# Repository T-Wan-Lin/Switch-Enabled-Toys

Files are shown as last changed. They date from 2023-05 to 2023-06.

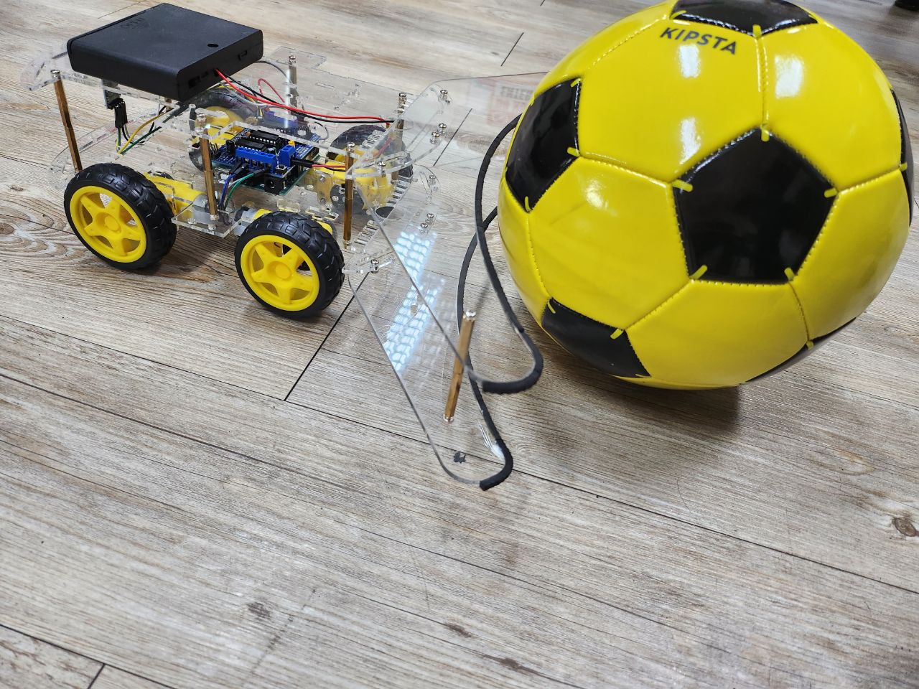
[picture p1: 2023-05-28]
docs/pictures/prototype_showcase/IMAGE 2023-05-28 16:13:55.jpg

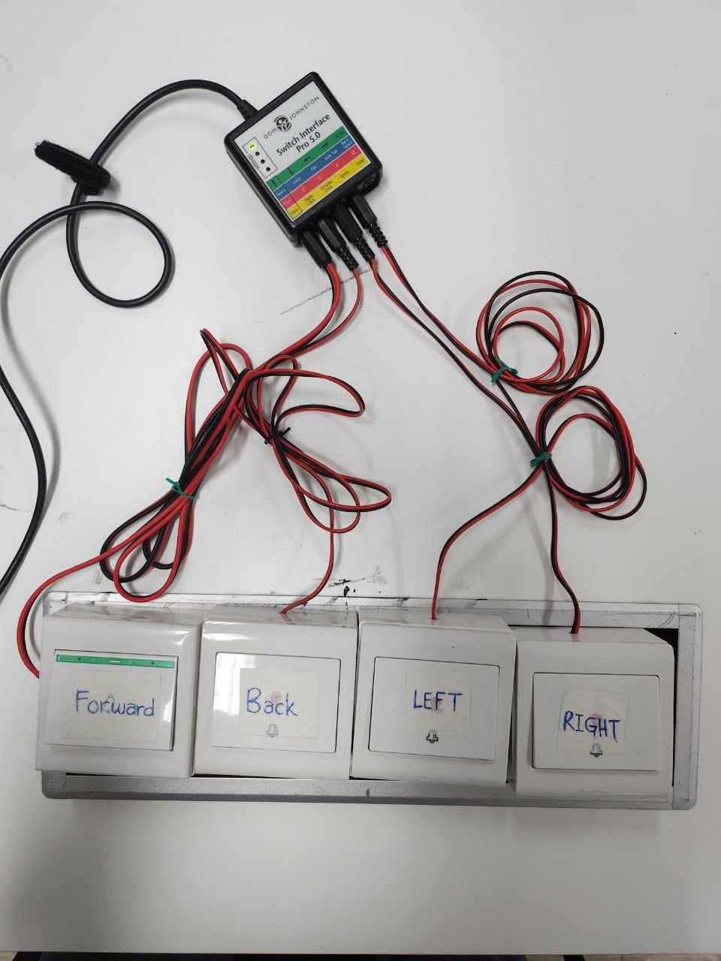
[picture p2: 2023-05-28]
docs/pictures/Switch Interface.jpg

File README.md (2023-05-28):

# Switch-Enabled-Toys: An EGSC Project done in collaboration with Rainbow Centre

## About EGSC 
EGSC (Engineering Good Student Chapters) is an initiative by Engineering Good, a Singapore-based non-profit organization. EGSC aims to engage students in engineering and technology fields to create positive social impact. Through their student chapters, they provide opportunities for students to collaborate, develop innovative solutions, and contribute to various social causes. Visit their [website](https://engineeringgood.org/about-us/student-chapters/) for more information.

## About Rainbow Centre
The Rainbow Centre, located in Singapore, is a non-profit organization dedicated to supporting individuals with disabilities and their families. Through a range of educational, therapeutic, and vocational services, they strive to empower individuals with special needs and promote their inclusion in society. Visit the [Rainbow Centre website](https://rainbowcentre.org.sg/) for more information.
 for more information.
## About the Project

The project focuses on creating switch-enabled toys for students of Rainbow Centre with multiple disabilities.
Due to their limited mobility, they are only able to watch from the sidelines as their peers engage in physical activities. 
We are currently working on a remote-controlled device that can be controlled by wheelchair-bound students to launch a ball into a net 
just by pressing a few buttons. We hope that with this device, they can engage more meaningfully in sports, 
and learn about directional changes as well as cause and effect.

For technical documentation, visit the `docs` [folder](https://github.com/T-Wan-Lin/Switch-Enabled-Toys/tree/docs/docs) in this repository. 

## Project members
The following are the contributing members to this project:

1. Tan Wan Lin

2. Kwa Minyi, Samantha

3. Cheran Lee Yen-ning

4. Hoe Mun

5. Pulipaka Sai Nandini

Should you need additional guidance, do not hesitate to contact us or raise an issue on Github.

## Acknowledgement

We would like to thank EGSC for giving us this invaluable opportunity as well as Mr Koh and Mr Khoo for their guidance.

Resources used:

How to build a DIY Bluetooth car: https://www.youtube.com/watch?v=Q36NbjPMV5k

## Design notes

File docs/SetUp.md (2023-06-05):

# Quick Start

## System requirements (should the designated device not be used)
1. Ensure that you have Python 3.70 (and above) installed. Visit this [site](https://www.python.org/downloads/release/python-370/) to install Python (including IDLE).
2. (Only if you have to upload the Arduino code, else, skip this step) Ensure that Arduino IDE is installed on your personal computer.
3. Ensure that these 2 python modules are installed: pyserial (using _pip install pyserial_ on commmand prompt) and pynput (using _pip install pynput_ on command prompt) for the program to run. (If pip is not recognised, use _py -m pip install [packagename]_ on command prompt instead)

## Instructions for use

 If the designated device is used,

1. Plug in the switch interface on the *RIGHT* USB port. This is the COM5 port that will be used for Bluetooth communication. Should any other USB ports be used, change the port number accordingly in the Controller.py file. To find which port the switch interface is connected to visit this [site](https://help.fleetmon.com/en/articles/2010900-how-do-i-get-my-com-port-number-windows)

2. Ensure that the computer's Bluetooth is ON and it is connected to a device named `HC-05`. Should you need a PIN to connect to the device, it is either `0000` or `1234`.

3. Plug the switches into the module. Ensure that the FIRST light on the switch interface module is GREEN as shown in this [picture](https://github.com/T-Wan-Lin/Switch-Enabled-Toys/blob/docs/docs/pictures/Switch%20Interface.jpg). If it is not, use the button on the top right corner of the switch module to switch between the modes.

4. Run the executable* file. Press the switches. Give the bot some time to receive the first signals (latency). If the executable file cannot be located, proceed to step 5.

5. Download the Controller.py file and put it in the Desktop directory (preferable). Open the file in IDLE. In the uppermost toolbar, click `Run` and in the dropdown, click `Run Module`. Should there be no errors, `Start` should be printed. Should there be errors (in red text) check if the relevant python modules are installed or if the Bluetooth connection is working. This step applies to other computers that are used other than the designated one.

6. Press the switches to move the bot. Give the bot some time to receive the first signals (latency).

*To create the executable file for easier usage of Controller.py file, the python module - pyinstaller has to be installed (using _pip install pyinstaller_ on command prompt). (If pip is not recognised, use _py -m pip install pyinstaller_ on command prompt instead) Subsequently, in command prompt, change to the directory of the Controller.py file (using _cd [file directory]_) and run the following code (_pyinstaller --onefile Controller.py_) [Reference: https://datatofish.com/executable-pyinstaller/]

## Uploading of Code 

NOTE: This section is relevant in the case the Arduino Board is forcefully reset.

Should the reset button be pressed on either the motor shield or the Arduino board, connect the Arduino Board with the black cable provided to your computer. 

Steps: 

1. Download the ENTIRE folder called `EGSC_car` from the G-Drive folder or this repository and place it in the Desktop directory.
2. Open it with Arduino IDE, which should be installed.
3. Follow the instructions provided at the top of the EGSC_car.ino file to install the libraries before the upload.
4. Select the correct board and port.
5. Upload the code. 

You may visit this [site](https://support.arduino.cc/hc/en-us/articles/4733418441116-Upload-a-sketch-in-Arduino-IDE) for more detailed steps on troubleshooting.

Back-up code can be found in [G-Drive folder](https://drive.google.com/drive/folders/1xDtzrKRc55RQwkxslrCCrbxYAzH-E_bL?usp=sharing)

## Glossary
1. IDE: Integrated Development Environment
2. IDLE: Python IDE

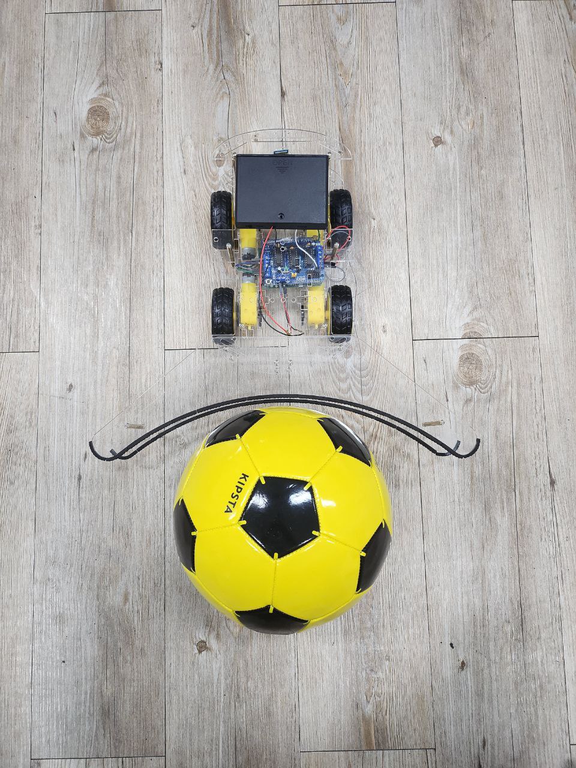
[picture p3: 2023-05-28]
docs/pictures/prototype_showcase/IMAGE 2023-05-28 16:13:47.jpg

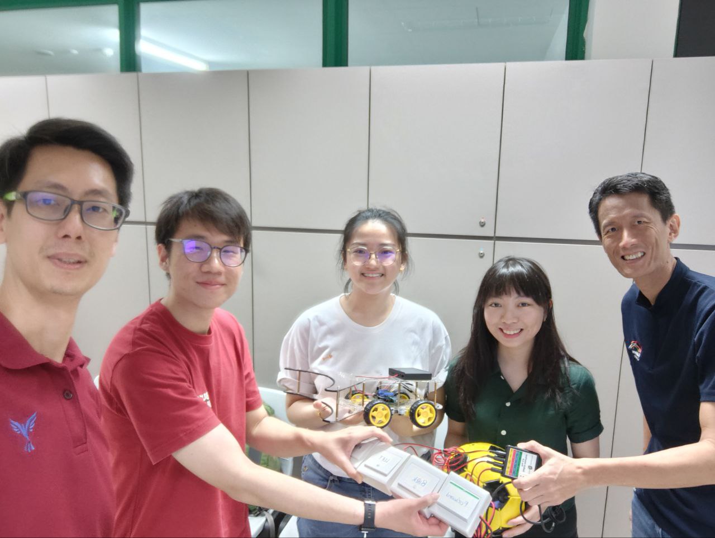
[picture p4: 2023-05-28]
docs/pictures/prototype_showcase/IMAGE 2023-05-28 16:19:57.jpg

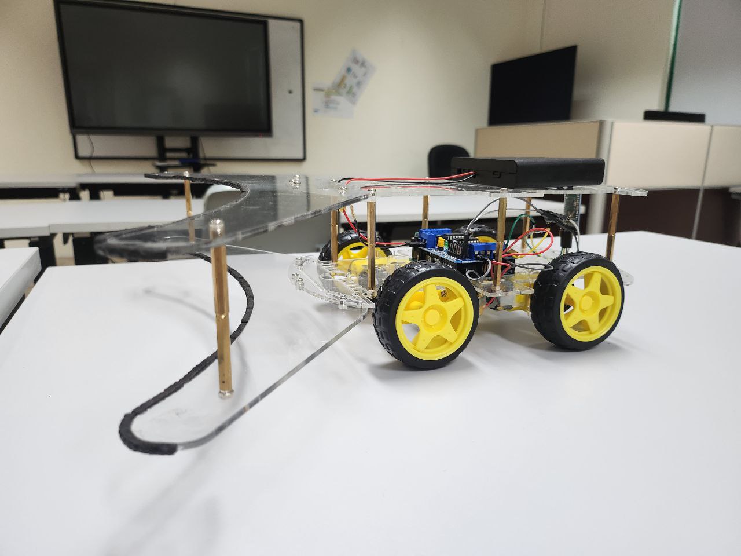
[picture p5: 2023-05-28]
docs/pictures/prototype_showcase/IMAGE 2023-05-28 16:13:51.jpg

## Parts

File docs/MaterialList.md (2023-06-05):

The following are the components used for the prototype:

|  No.  | Materials | Quantity  |
| :---: | :---: | :---: |
| 1 | Acrylic Chassis | 2* |
| 2 | Wheel | 4 |
| 3 | AA Batteries** | 6 |
| 4 | AA Battery Pack | 1 |
| 5 | Jumper Wires | As needed |
| 6 | C-frame*** | 2 |
| 7 | Rubber Lining along C-frame | As needed |
| 8 | Arduino Uno | 1 |
| 9 | Arduino L293D DC Motor Driver Shield | 1 |
|  10 | HC-05 Bluetooth Module | 1 |
|  11 | Nuts, bolts, hex brass screws | As needed |
|  12 |  Don Johnston Switch Interface Pro | 1 |
|  13 | Switches | 4 |
|  14 | Motor | 4 |

```
* One for lower and one for upper deck 

** Note: 9V is the minimum voltage needed to power the prototype but cannot be replaced with a single 9V battery 
cell due to limitations uncovered during real-life testing.

*** Using the c-frame dxf file, laser cut on acrylic sheet 
```

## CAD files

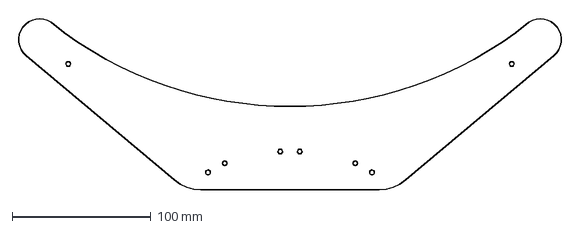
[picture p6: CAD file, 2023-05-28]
docs/cframe/C-Frame.dxf
394.1 x 124.8 mm

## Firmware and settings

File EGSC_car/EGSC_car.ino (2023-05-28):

//Arduino Bluetooth Controlled Car
//Before uploading the code you have to install the necessary library
//AFMotor Library https://learn.adafruit.com/adafruit-motor-shield/library-install 
//ENSURE THAT THE BLUETOOTH MODULE IS DISCONNECTED FROM THE BOARD BEFORE UPLOAD. To do so, simply disconnect either one of the jumper wires.

#include <AFMotor.h>

//initialise motors pin
AF_DCMotor motor1(1, MOTOR12_1KHZ); 
AF_DCMotor motor2(2, MOTOR12_1KHZ); 
AF_DCMotor motor3(3, MOTOR34_1KHZ);
AF_DCMotor motor4(4, MOTOR34_1KHZ);

char command; 

void setup() 
{       
  Serial.begin(9600);  //Set the baud rate to your Bluetooth module.
}

void loop(){
  if(Serial.available() > 0){ 
    command = Serial.read(); 
    Stop(); //initialize with motors stoped
    //Change pin mode only if new command is different from previous.   
    //Serial.println(command);
    switch(command){
    case 'F':  
      forward();
      break;
    case 'B':  
       back();
      break;
    case 'L':  
      left();
      break;
    case 'R':
      right();
      break;
    }
  } 
}

void forward()
{
  motor1.setSpeed(255); //Define maximum velocity
  motor1.run(FORWARD); //rotate the motor clockwise
  motor2.setSpeed(255); //Define maximum velocity
  motor2.run(FORWARD); //rotate the motor clockwise
  motor3.setSpeed(255);//Define maximum velocity
  motor3.run(FORWARD); //rotate the motor clockwise
  motor4.setSpeed(255);//Define maximum velocity
  motor4.run(FORWARD); //rotate the motor clockwise
}

void back()
{
  motor1.setSpeed(255); //Define maximum velocity
  motor1.run(BACKWARD); //rotate the motor anti-clockwise
  motor2.setSpeed(255); //Define maximum velocity
  motor2.run(BACKWARD); //rotate the motor anti-clockwise
  motor3.setSpeed(255); //Define maximum velocity
  motor3.run(BACKWARD); //rotate the motor anti-clockwise
  motor4.setSpeed(255); //Define maximum velocity
  motor4.run(BACKWARD); //rotate the motor anti-clockwise
}

void left()
{
  motor1.setSpeed(255); //Define maximum velocity
  motor1.run(BACKWARD); //rotate the motor anti-clockwise
  motor2.setSpeed(255); //Define maximum velocity
  motor2.run(BACKWARD); //rotate the motor anti-clockwise
  motor3.setSpeed(255); //Define maximum velocity
  motor3.run(FORWARD);  //rotate the motor clockwise
  motor4.setSpeed(255); //Define maximum velocity
  motor4.run(FORWARD);  //rotate the motor clockwise
}

void right()
{
  motor1.setSpeed(255); //Define maximum velocity
  motor1.run(FORWARD); //rotate the motor clockwise
  motor2.setSpeed(255); //Define maximum velocity
  motor2.run(FORWARD); //rotate the motor clockwise
  motor3.setSpeed(255); //Define maximum velocity
  motor3.run(BACKWARD); //rotate the motor anti-clockwise
  motor4.setSpeed(255); //Define maximum velocity
  motor4.run(BACKWARD); //rotate the motor anti-clockwise
} 

void Stop()
{
  motor1.setSpeed(0); //Define minimum velocity
  motor1.run(RELEASE); //stop the motor when release the button
  motor2.setSpeed(0); //Define minimum velocity
  motor2.run(RELEASE); //rotate the motor clockwise
  motor3.setSpeed(0); //Define minimum velocity
  motor3.run(RELEASE); //stop the motor when release the button
  motor4.setSpeed(0); //Define minimum velocity
  motor4.run(RELEASE); //stop the motor when release the button
}

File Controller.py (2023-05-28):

import serial
import time
from pynput import keyboard
 
evenement=""
print("Start")
port="COM3" #This will be different for various devices and on windows it will probably be a COM port. CHANGE THIS LINE ONLY
bluetooth=serial.Serial(port, 9600)#Start communications with the bluetooth unit
print("Connected")
bluetooth.flushInput() #This gives the bluetooth a little kick
result = str(0)
 
def on_key_release(key):
    global result
    #print('released %s' % key)
    #result ='released %s' % key+'\n'
    if result !='stop': #or result == str(2)+'\n' or result == str(3)+'\n' or result == str(4)+'\n':
       result = 'stop'
       print(result)
       result_bytes = result.encode('utf_8')
       bluetooth.write(result_bytes)
 
def on_key_pressed(key):
    global result       
    #print('pressed %s' % key)
    result1 ='%s' % key
    if result == 'stop':
        if result1=='Key.up' :
           result = 'F'
           print(result)
        if result1=='Key.down' :
           result = 'B'
           print(result)
        if result1=='Key.left' :
           result = 'R'
           print(result)
        if result1=='Key.right' :
           result = 'L'
           print(result)         
        result_bytes = result.encode('utf_8')
        bluetooth.write(result_bytes)
 
with keyboard.Listener(on_release = on_key_release,on_press=on_key_pressed) as listener:
    listener.join()

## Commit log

2023-01-04 Videos of very first prototype
2023-05-28 Update README and material list
2023-05-28 Add pictures of prototype
2023-05-28 Update Material List
2023-05-28 Add dxf file for cframe
    [C-Frame.dxf]
2023-05-29 MaterialList.md
    Additional materials and pointers
